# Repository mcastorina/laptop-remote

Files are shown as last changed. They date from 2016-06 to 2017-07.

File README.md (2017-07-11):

# laptop-remote

## What is it?
This is a simple project that combines a [Trellis button
pad](https://www.adafruit.com/products/1616) and a [nRF8001 BlueTooth
Low Energy](https://www.adafruit.com/products/1697) breakout in order
to run commands remotely on my (linux) laptop. This project uses the
Arduino Uno for the remote, and a shell script as the receiver.

## Motivation
I thought it would be cool to control my laptop when watching a movie
or other media. It also served as a learning experience for the BLE
protocol.

## Dependencies
Arduino Libraries:

* [Adafruit Trellis](https://github.com/adafruit/Adafruit_Trellis_Library)
* [Adafruit BLE UART](https://github.com/adafruit/Adafruit_nRF8001)

Linux commands:

* gatttool

## Status
- [x] Working prototype on breadboard
- [x] Transfer off of Arduino board
- [x] Design PCB
- [ ] Design case
- [ ] Etch PCB
- [ ] Build case
- [ ] Done!

## Future Goals
Because it uses BlueTooth, it doesn't matter /what/ exactly is connecting
to my laptop. That being said, I might write an Android application to
do the same.

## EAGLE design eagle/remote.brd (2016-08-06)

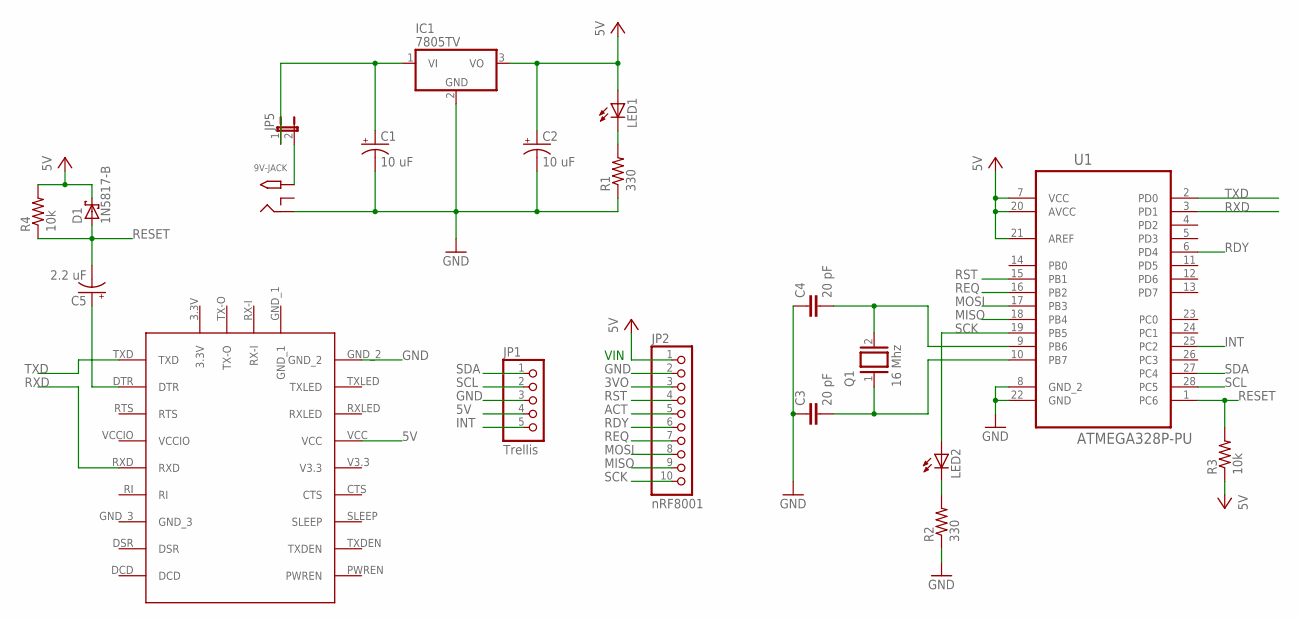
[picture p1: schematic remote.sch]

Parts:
9V-JACK: 9V Input; PJ-102A
C1, C2: 10 uF; B45181B
C3, C4: 20 pF; C050-025X075
C5: 2.2 uF; B45181B
D1: 1N5817-B; DO41-7.6
IC1: 7805TV; TO220V
JP1: Trellis; 1X05
JP2: nRF8001; 1X10
JP5: JP1E; JP1
LED1, LED2: LED3MM
Q1: 16 Mhz; QS
R1, R2: 330; RES400MIL
R3, R4: 10k; RES400MIL
U1: ATMEGA328P-PU; DIP254P762X457-28
U$1: FT232

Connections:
3VO: JP2.3
5V: C2.+, D1.C, IC1.3 (VO), JP1.4, JP2.1, LED1.A, R3.1, R4.2, U1.7 (VCC), U1.20 (AVCC), U1.21 (AREF), U$1.VCC
ACT: JP2.5
GND: 9V-JACK.RING, C1.-, C2.-, C3.1, C4.1, IC1.2 (GND), JP1.3, JP2.2, R1.1, R2.1, U1.8 (GND_2), U1.22 (GND), U$1.GND_2
INT: JP1.5, U1.25 (PC2)
MISO: JP2.9, U1.18 (PB4)
MOSI: JP2.8, U1.17 (PB3)
unnamed: C1.+, IC1.1 (VI), JP5.1
unnamed: LED1.K (C), R1.2
unnamed: C3.2, Q1.1, U1.10 (PB7)
unnamed: C4.2, Q1.2, U1.9 (PB6)
unnamed: C5.+, U$1.DTR
unnamed: 9V-JACK.TIP, JP5.2
unnamed: LED2.K (C), R2.2
RDY: JP2.6, U1.6 (PD4)
REQ: JP2.7, U1.16 (PB2)
RESET: C5.-, D1.A, R3.2, R4.1, U1.1 (PC6)
RST: JP2.4, U1.15 (PB1)
RXD: U1.3 (PD1), U$1.RXD
SCK: JP2.10, LED2.A, U1.19 (PB5)
SCL: JP1.2, U1.28 (PC5)
SDA: JP1.1, U1.27 (PC4)
TXD: U1.2 (PD0), U$1.TXD

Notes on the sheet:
VIN

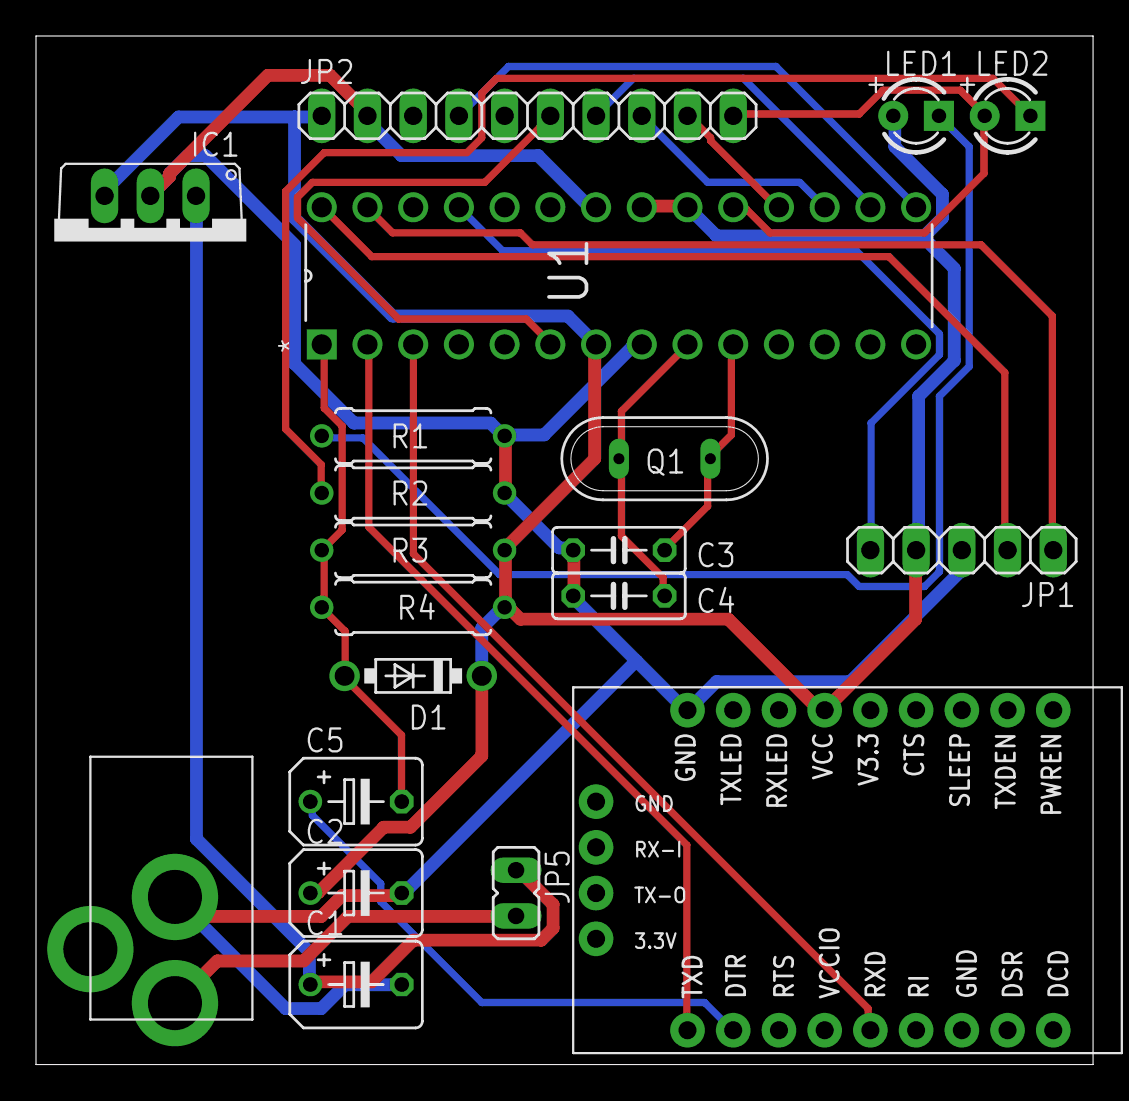
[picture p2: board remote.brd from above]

Board: 2 copper layers, 58.7 x 57.1 mm, 20 parts (0 on the bottom side), 21 nets.

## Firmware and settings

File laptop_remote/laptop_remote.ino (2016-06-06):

// This version uses the internal data queing so you can treat it like
// Serial (kinda)!

#include <SPI.h>
#include <Wire.h>
#include "Adafruit_Trellis.h"
#include "Adafruit_BLE_UART.h"

#define DEBUG

/* BLE defines */
// Connect CLK/MISO/MOSI to hardware SPI
// e.g. On UNO & compatible: CLK = 13, MISO = 12, MOSI = 11
#define ADAFRUITBLE_REQ     10
#define ADAFRUITBLE_RDY     2   // This should be an interrupt pin (2 or 3)
#define ADAFRUITBLE_RST     9

/* Trellis defines */
#define NUMTRELLIS          1
#define NUMKEYS             (NUMTRELLIS * 16)
#define INTPIN              A2  // can change
// SDA pin to I2C SDA line (A4)
// SCL pin to I2C SCL line (A5)

Adafruit_Trellis matrix0 = Adafruit_Trellis();
Adafruit_TrellisSet trellis = Adafruit_TrellisSet(&matrix0);

Adafruit_BLE_UART BTLEserial =
    Adafruit_BLE_UART(ADAFRUITBLE_REQ, ADAFRUITBLE_RDY, ADAFRUITBLE_RST);

// array of times of our first presses of a key
// used for keeping track of when to constantly send
long first_presses[NUMKEYS];
long global_count;

void setup(void) {
#ifdef DEBUG
    Serial.begin(115200);
    while(!Serial);
    Serial.println(F("BLE Trellis Remote Control"));
#endif
    /* BLE setup */
    BTLEserial.begin();
    BTLEserial.setDeviceName("Dennis"); /* 7 characters max! */

    /* Trellis setup */
    // INT pin requires a pullup
    pinMode(INTPIN, INPUT);
    digitalWrite(INTPIN, HIGH);

    // begin() with the addresses of each panel in order
    trellis.begin(0x70);
    trellis.setBrightness(3);   // 15 is max

    // count used for button timing, increases every loop()
    global_count = 0;
}

aci_evt_opcode_t laststatus = ACI_EVT_DISCONNECTED;

void loop() {
    // Tell the nRF8001 to do whatever it should be working on
    BTLEserial.pollACI();

    // Ask what is our current status
    aci_evt_opcode_t status = BTLEserial.getState();
    // If the status changed....
    if (status != laststatus) {
        if (status == ACI_EVT_DEVICE_STARTED) {
#ifdef DEBUG
            Serial.println(F("* Advertising started"));
#endif
            ble_disconnected();
        }
        if (status == ACI_EVT_CONNECTED) {
#ifdef DEBUG
            Serial.println(F("* Connected!"));
#endif
            ble_connected();
        }
        if (status == ACI_EVT_DISCONNECTED) {
#ifdef DEBUG
            Serial.println(F("* Disconnected or advertising timed out"));
#endif
            ble_disconnected();
        }
        // Set the last status change to this one
        laststatus = status;
    }

    if (status == ACI_EVT_CONNECTED) {
        // Lets see if there's any data for us!
        if (BTLEserial.available()) {
#ifdef DEBUG
            Serial.print("* ");
            Serial.print(BTLEserial.available());
            Serial.println(F(" bytes available from BTLE"));
#endif
            // Get characters
            while (BTLEserial.available()) {
                char data = 0;
                char cmd = BTLEserial.read();
                if (BTLEserial.available())
                    data = BTLEserial.read();
#ifdef DEBUG
                Serial.print(cmd + " : " + data);
#endif
                uint8_t led = cmd;
                uint8_t val = data;

                if (val) trellis.setLED(led);
                else     trellis.clrLED(led);
            }
            trellis.writeDisplay();
        }

        // Go through every button update LEDs
        if (trellis.readSwitches()) {
            for (int i = 0; i < NUMKEYS; i++) {
                if (trellis.isKeyPressed(i))    trellis.setLED(i);
                else                            trellis.clrLED(i);
            }
            trellis.writeDisplay();
        }

        // Go through every button
        for (int i = 0; i < NUMKEYS; i++) {
            if (trellis.isKeyPressed(i)) {
                uint8_t cmd = i;
                if (trellis.justPressed(i)) {
                    first_presses[cmd] = global_count;

                    // write the data
                    BTLEserial.write(&cmd, 1);
#ifdef DEBUG
                    Serial.print(F("* Sending -> \""));
                    Serial.print((char)(cmd + 0x30));
                    Serial.println("\"");
#endif
                }
                else if (first_presses[cmd] < global_count - 20) {
                    // write the data if it has been ~600 ms since first press
                    BTLEserial.write(&cmd, 1);
#ifdef DEBUG
                    Serial.print(F("* Sending -> \""));
                    Serial.print((char)(cmd + 0x30));
                    Serial.println("\"");
#endif
                }
#ifdef DEBUG
                Serial.print(F("* Button pressed -> "));
                if (cmd >= 10) Serial.print((char)((cmd/10) + 0x30));
                Serial.println((char)((cmd%10) + 0x30));
#endif
            }
        }
    }
    global_count++;
    delay(30);  // 30ms delay is required for Trellis
}

void ble_connected(void) {
    // light up all the LEDs in order
    for (int i = 0; i < NUMKEYS; i++)
        trellis.clrLED(i);
    trellis.writeDisplay();

    for (int i = 0; i< NUMKEYS; i++) {
        trellis.setLED(i);
        trellis.writeDisplay();
        delay(50);
    }

    delay(700);
    for (int i = 0; i < NUMKEYS; i++)
        trellis.clrLED(i);
    trellis.writeDisplay();
}
void ble_disconnected(void) {
    // blink all the LEDs
    for (int i = 0; i < NUMKEYS; i++)
        trellis.setLED(i);
    trellis.writeDisplay();

    delay(10);
    for (int i = 0; i < NUMKEYS; i++)
        trellis.clrLED(i);
    trellis.writeDisplay();
}

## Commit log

2016-05-19 Initial commit.
    The current arduino sketch interfaces with the Trellis 4x4 touchpad and
    the nRF8001 BlueTooth Low Energy breakout and sends the key press to the
    laptop (running receiver.sh). The receive script does nothing with the
    values it receives.
2016-05-19 Setup framework for parsing receiver input.
2016-05-19 WIP on arduino code and receiver script.
    Arduino code will now constantly send values if the button is still
    pressed, and the receiver will execute 'xdotool' commands to the move
    the mouse or press keys.
2016-05-20 Receiver is now mapped, and arduino sketch resends button well.
    The receiver script is now mapped to a useful set of commands, and the
    arduino sketch will resend button presses after ~600 ms.
    Overall, it works well, however there is a large flaw: The arduino is
    the one that is advertising and the receiver must connect to it. In
    other words, the remote cannot reconnect to the receiver after turning
    off and back on again.
    One way to fix this is to have the receiver periodically reconnect.
    Another way is to have the receiver advertise and the controller
    connect.
    [laptop_remote.ino]
2016-06-06 Changed some of the command bindings.
    [laptop_remote.ino]
2016-07-09 Added eagle schematic and pcb files
    [remote.brd, remote.sch]
2016-08-06 Reworked PCB so it is smaller.
    Because I plan to order the PCB using www.oshpark.com, I used two layers
    and tightened everything up.
    [remote.brd, remote.sch]
